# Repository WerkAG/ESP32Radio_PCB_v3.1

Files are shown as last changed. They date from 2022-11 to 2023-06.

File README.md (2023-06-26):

# ESP32Radio-V2, PCB v3.x
## Printed Circuit Board for the [ESP32Radio-V2 from Ed Smallenburg](https://github.com/Edzelf/ESP32Radio-V2)

Updates:
- 2023-06-26, PCB v3.1 Rev C assembled with all SMD parts is now available by request. 
- 2022-11-06, PCB v3.1 Rev C

 ** **
 
As microcontroller this PCB uses the MH ET LIVE ESP32MiniKit.<br> 
The PCB is designed to allow the use of one mini amplifier module (PAM8403) and/or a bluetooth transmitter module (kcx_bt_emitter).<br>
There are connectors for the supported display types (TFT, LCD, Nextion not tested), the rotary encoder, the IR receiver plus a expansion port with pins connected to GPIO12, GPI013, GPIO14 and GPIO34. MISO, MOSI, SLCK pins are also available on the expansion port.<br>
Circuit to turn ON/OFF the TFT backlight is also implemented. Control is done by the ESP32Radio software.<br>
Power supply is 5V DC.<br>
<br>

ESP32_WebRadio_PCB_v3 2_02
 <br>
 ** **

**Example of one unit using the PAM8403 amplifier.** <br><br>
The black wire on the picture isn't a patch, it connects the Analog GND (GBUF) from the VS1053 through a 47uF capacitor to VREF (pin 8) of the PAM8403 chip. This effectively cancels any noise on the speakers.<br>
Many hobbyists are hiding the huge problem of connecting an amplifier directly to the output of the VS1053B module. Everyone plugs in the headphones or amplifiers with a separate power supply and is happy with it. The problem is that as soon as you connect an amplifier with common ground to the VS1053 module, you hear very strong digital noise, which even drowns out the useful signal.<br>

ESP32_WebRadio_PCB_v3 2_03
 <br>
 ** **

**Example of a second unit using the kcx_bt_emitter bluetooth module.** <br>


<br>

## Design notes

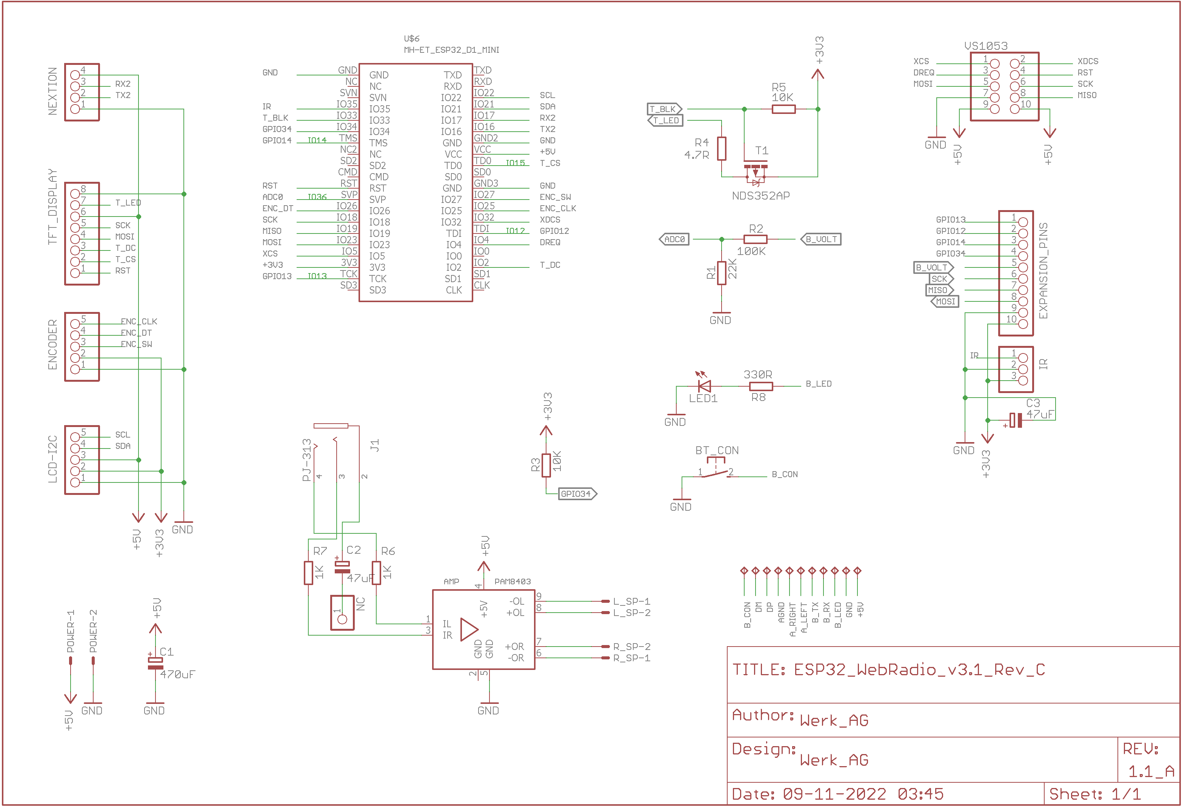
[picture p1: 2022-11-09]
doc/ESP32Radio_PCB_v3.1_Rev_C_Schematic.png

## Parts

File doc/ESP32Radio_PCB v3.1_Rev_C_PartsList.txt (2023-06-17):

ESP32Radio PCB v3.1 Rev C

PARTS LIST

RESISTORS SMD 0805
R1 22K
R2 100K
R3 10K
R4 4.7R
R5 10K
R6 1K
R7 1K
R8 330R

CAPACITORS
C1 470uF/16V
C2 47uF/16V
C3 220uF/16V

TRANSISTORS
T1 NDS352AP

LED
3mm Blue Led (optional)

MISC PARTS
MH ET LIVE ESP32MiniKit
VS1053 module
3.5mm Stereo Jack PJ-313
everal 2.54mm male pin headers
3 x KF128 2 pin screw connectors (2.54mm)
Push Buttom (optional)

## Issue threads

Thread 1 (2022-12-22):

KCX_BT_EMITTER details

willemneethling, 2022-12-22:
Thanks for providing your design. I am interested in your use of the KCX_BT_EMITTER. I checked your schematic but I don't see the BT module listed, other than a mention of the BT connect button. Also, as far as I know, Edzelf ESP radio doesn't support this module, did you change the code to support it? If so, is it possible to share the schematic and code changes?

WerkAG, 2022-12-23:
Hi,

To use the KCX_BT_EMITTER, there is no need to do any change on the original software from Edzelf ESP32Radio software. Instead of use the PAM8403, just solder the KCX_BT_EMITTER on the PCB. The BT button is only for pairing the KCX_BT_EMITTER module with your speakers or BT receiver.
Thank you for your interest on this PCB.

willemneethling, 2022-12-30:
Thank you very much for the clarification

WerkAG, 2022-12-30:
As this info can be useful to others, let's keep it open.

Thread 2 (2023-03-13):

Do I need the SMD parts?

HaViGit, 2023-03-13:
Thanks for sharing the PCB, I'm about to order from JLCPCB. Just a question in advance, I have only little experience with SMD soldering and wonder if I need the resistors and transistors. It is planned to use Ed's radio without a PAM amplifier, but with the rotary encoder, the BlueTFT and perhaps the Bluetooth transmitter (which needs SMD mounting).

I like to hear from you!

WerkAG, 2023-03-13:
Hi,

Thanks for your interest on this PCB.
At least you will need to install R4, R5 and T1, otherwise the TFT backlight will not lit.

Rgs.

HaViGit, 2023-03-13:
Thanks for your reply. Maybe it's time for me to gain experience with SMD techniques and your PCB is a good and pleasant reason. So today I ordered the PCB, SMD tools including a hotplate and the necessary parts ;-)

WerkAG, 2023-03-14:
Soldering SMD parts its easy than it seems, you only need a soldering iron with a thin point, and a magnifying glass. If you would like post a picture of the end result.
Thank you.
Rgs.

HaViGit, 2023-03-14:
If the end result is neat I'll post a picture ;-)

WerkAG, 2023-03-14:
👍

HaViGit, 2023-03-30:
Here's the result of my first SMD project, I'm not disappointed. The resistors R1 and R2 are not mounted because I do not use the voltage divider.

Thanks for sharing the Gerber!

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

WerkAG, 2023-03-31:
It looks pretty good. Soon will be finished and playing music. Thank you too for the picture.

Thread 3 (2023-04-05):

Bluetooth issues

HaViGit, 2023-04-05:
Did you discover issues using the Bluetooth transmitter? Please see https://github.com/Edzelf/ESP32Radio-V2/issues/92.

WerkAG, 2023-04-06:
Can you post a link to the specs of the Bluetooth transmitter module you are using? It is not an KCX_BT_EMITTER module like the ones I'm using, but I suppose you have checked compatibility. Yours seems to have a jumper to set RX / TX mode, is it in TX mode?

HaViGit, 2023-04-06:
I bought the BT module from AliExpress (see below) and I hadn't noticed that it was different from yours. The PIN layout is the same and if the jumper is open it is in TX mode so that should be OK. If I see correctly, the chip is a BPOW17, but I can't find anything about it on the Internet, so no datasheet either. Perhaps this BT module only works after receiving AT commands.

Maybe it's better to order the module you use and see if that works.

[https://www.aliexpress.com/item/1005003224071356.html](url)

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

WerkAG, 2023-04-08:
From what I saw from your link, your module is  newer (v1.7 bluetooth 5.1) than  mine, which is v1.1 bluetooth 4.1. As you said pinout is the same, so I suppose it should work too. Is the LED linking in RED or BLUE? From specs RED means TX.
I had some difficulties on pairing mine with some devices, but once paired I got sound.

HaViGit, 2023-04-08:
I would also be surprised if the two version modules are not compatible, nevertheless I ordered two like you used to make sure that is not the issue.

The LED does indeed flash red and after pairing the LED on your PCB will also turn on. When I turn the earbuds or headphones on or off, that LED responds as expected. So I don't think pairing is the problem.

Anyway I will have to wait for the new BT modules to arrive, I will let you know what the result is afterwards.

HaViGit, 2023-04-08:
Thank you for your message. I know it is sometimes difficult to pair BT but the pairing works fine, just no sound. In the meantime I tested with Samsung Earbuds, a Sony Headphone and a set of very cheap earbuds from AliExpress. I can pair them all, pretty quickly, but no sound.

Maybe I have a faulty module, maybe there is another problem with my version. All I can do now is to be patient and wait for the old version to be delivered. Besides the radio works well through a pair of wired speakers ;-)

WerkAG, 2023-04-10:
It should not make any difference, but try to remove the C2 cap, it isn't needed for bluetooth operation.

HaViGit, 2023-04-10:
As you expected, it made no difference. I'm patient so now wait a while until the other module is received.

HaViGit, 2023-04-20:
Today the ordered BT modules were delivered, but contrary to what was advertised on AliExpress, they did not send the old but the new version. So I don't get anywhere with that, I opened a dispute on AliExpress. In short, I can't go on with it. I'm going to put this project on hold for now :-(

WerkAG, 2023-04-20:
I'm so curious, that as soon as possible I will order one of these new versions.

HaViGit, 2023-04-25:
After I paired my earbuds with the BT module, I still didn't hear any music on the earbuds. But while I was doing some testing and experimenting I accidentally connected AGND on the BT module to GND (power negative) of the ESP-32 board. Immediately afterwards, playback started on my earbuds.

To exclude that I did something wrong during the soldering and to be sure that I did not use a defective BT module, I built a second radio. There too BT audio only worked after I made a permanent connection between GND and AGND.

I assume this has to do with the newer version of the BT module, after all I used a different one than you (see above). Anyway, my project is now successful!

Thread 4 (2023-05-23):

Type of capacitor

z34pec, 2023-05-23:
Hello. In your explanation is said to connect cap 74uF but it is not defined is it electrolytic or normal, block (ceramic) and voltage of it  ?
On your pic I see only electrolytic so I suppose it is electrolytic up to 16v or more ?
Also

WerkAG, 2023-05-25:
Hi. I used 47uF electrolytic, and it worked fine. I think you can use also 33uF or even 22uF.
Thanks.

z34pec, 2023-05-27:
Hello.
Thank you for explanation.
I check vs1053 documentation and it says GBUF is GND from output to headphones, right ?
So I have to connect this capacitor between GND of headphones and pin 8 of PAM8403 chip, right ?

WerkAG, 2023-05-28:
If you are using the PCB, use a small wire to connect the point marked with NC on the PCB to pin 8 of PAM8403 chip, if not,  connect the GND (that is GBUF) from output to headphones on the vs1053 module to positive pole of the capacitor and the negative pole to pin 8 of PAM8403 chip.

z34pec, 2023-05-28:
Thank you for your response.
I will do it as soon as possible.
73 de Z34PEC
Petrika

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

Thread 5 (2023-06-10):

5V dc source

RobiDobo, 2023-06-10:
Can I do this without having a 5v dc source? Other esp32 dev boards have the pin for 5V but I dont see it on this one. Can I use a normal esp32 and power it externally? The design looks really good too, sorry if this is offtopic i'm a beginner.

WerkAG, 2023-06-12:
The ESP32 board used on this project also have a 5V input pin. You will need a 5V DC source, that you can connect to the 5V power input on the PCB.
Thanks.

RobiDobo, 2023-06-12:
Thanks much.

RobiDobo, 2023-06-12:
Also, can you please tell me if I can use a PAM8403 with a built in potentiometer?

WerkAG, 2023-06-13:
If you understood what is said about the common ground issue and know how to correctly connect the PAM8403 with a built in potentiometer, I think you can. I just can comment on this project as it is, any changes you need to try by yourself.

Any 5V power supply with at least 1Amp should work.

RobiDobo, 2023-06-13:
I think I understand, looking at a couple of projects some use audio transformers to eliminate the noise, while you use capacitors. I will try this, thank you a lot for the files and help.

WerkAG, 2023-06-15:
The trick is not the capacitor, but not mix the GND of the general circuit with the Analog GND (GBUF) from the VS1053.

RobiDobo, 2023-06-15:
That makes sense! Thank you for clarification. I can't help but notice in the part list it says 0806 SMD resistors, but on the internet i could only find 0805 SMD. What's the deal there?

WerkAG, 2023-06-17:
You are helping :-) The resistors are 0805, it was a typo error. Already corrected, thank you.

Closed 2023-09-24.

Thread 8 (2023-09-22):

LineIn

RobiDobo, 2023-09-22:
How do you connect the vs1053 on the pcb? I have the LINE IN pins sticking out.

WerkAG, 2023-09-22:
The easy way is using a small cable with a male jack on both ends. LINE OUT of the VS1053 to LINE IN on the board. See the pictures, they illustrate it better than my words.

RobiDobo, 2023-09-22:
Thank you but I still can't see what to connect it to. LINE IN of vs1053 should go to Line out on the board right? But I can't see anything labelled as "line out" or "line in" on the pcb. Pls help I'm confused where to look even after reading several times :)

WerkAG, 2023-09-23:
The 3.5mm stereo jack on the board is the LINE IN. The 3.5mm jack on the VS1053 in LINE OUT. Just connect the two with a small 3.5mm stereo male-male cable

Note: The reason for having the small the 3.5mm stereo jack on the board is to allow the device to work with other sound sources than just the VS1053. It will amplify or transmit by Bluetooth whatever you put on the LINE IN of the board.

Sorry for my poor English.

RobiDobo, 2023-09-23:
Ah okay I see, I will do that but there are also 2 pins on the VS1053 beneath which is written LINE IN and I don't see anything in the scheme what to do with those. Don't worry, your english is very clear.

WerkAG, 2023-09-23:
The line in pins on the VS1053 (decoder board) aren't used for anything.

RobiDobo, 2023-09-23:
then should I cut them or how do i fit the vs1053 on the pcb? use female headers and leave those pins sticking out?

RobiDobo, 2023-09-23:
Thank you very much for bearing with me :)

WerkAG, 2023-09-23:
Yes, use female headers on the PCB, then fit the VS1053 module on them. The VS1053 module will be removable.
I suggest to also use female headers for the microcontroller.
:-)

RobiDobo, 2023-09-24:
Thank you!

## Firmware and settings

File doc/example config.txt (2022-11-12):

clk_dst = 1                 # Offset during daylight saving time (hours)
clk_offset = 0              # Offset with respect to UTC in hours
clk_server = pool.ntp.org   # Time server to be used
#
ir_02FD = preset = 25       # Button 4
ir_20DF = mute
ir_38C7 = preset = 1        # Button 1
ir_40BF = upvolume = 2
ir_609F = uppreset = 1
ir_629D = preset = 9        # Button 9
ir_A25D = preset = 23       # Button 8
ir_C03F = downvolume = 2
ir_E01F = downpreset = 1
ir_E21D = preset = 0        # Button 8
#
mqttbroker = none
mqttpasswd = none
mqttport = 1883
mqttprefix = none
mqttuser = none
#
pin_enc_clk = 25           # GPIO Pin for rotary encoder "CLK"
pin_enc_dt = 26            # GPIO Pin for rotary encoder "DT"
pin_enc_sw = 27            # GPIO Pin for rotary encoder "SW"
pin_ir = 35                # GPIO Pin for IR receiver VS1838B
pin_tft_blx = 33
pin_tft_cs = 15            # GPIO Pin for TFT "CS"
pin_tft_dc = 2             # GPIO Pin for TFT "DC"
pin_vs_cs = 5              # GPIO Pin for VS1053 "CS"
pin_vs_dcs = 32            # GPIO Pin for VS1053 "DCS"
pin_vs_dreq = 4            # GPIO Pin for VS1053 "DREQ"
#
preset = 11
preset_000 = pianosolo.streamguys.net/live                      # 00- Solo Piano Radio
preset_001 = radiocast.rtp.pt/antena180a.mp3                    # 01- Antena 1
preset_002 = radiocast.rtp.pt/antena280a.mp3                    # 02- Antena 2
preset_003 = radiocast.rtp.pt/antena380a.mp3                    # 03- Antena 3
preset_004 = mcrscast.mcr.iol.pt/m80                            # 04- M80
preset_005 = mcrscast.mcr.iol.pt/smoothfm                       # 05- Smooth FM
preset_006 = 20863.live.streamtheworld.com/RFM_SC               # 06- RFM
preset_007 = tsfdirecto.tsf.pt/tsfdirecto.mp3                   # 07- TSF
preset_008 = radiocast.rtp.pt/antena2jazzin80a.mp3              # 08- JazzIn
preset_009 = strm112.1.fm/rockclassics_mobile_mp3               # 09- 1.FM Classic Rock
preset_010 = streaming.hotmix-radio.net/hotmixradio-90-128.mp3  # 10- Hotmix Radio 90s
preset_011 = airspectrum.cdnstream1.com:8114/1648_128           # 11- Easy Hits Florida 128k
preset_012 = airspectrum.cdnstream1.com:8000/1261_192           # 12- Magic Oldies Florida
preset_013 = strm112.1.fm/crock_mobile_mp3                      # 13- 1.FM Classic Rock Replay
preset_014 = 178.32.111.41:8039/stream-128kmp3-HealingMusic     # 14- Relaxing Music
preset_015 = streams.radiobob.de/bob-80srock/mp3-192/streams.radiobob.de   # 15- Radio Bob
preset_016 = streamer.radio.co/sa7bf61271/listen                           # 16- JB's Rock N Roll
preset_017 = air-tunein.radioart.com/fAura.mp3                # 17- RadioArt - Aura
preset_018 = stream12.iloveradio.de/iloveradio2-aac.mp3       # 18- Radio Dance Music
preset_019 = 174.36.206.197:8000/stream                       # 19- Venice Classic Radio
preset_020 = ice6.somafm.com/suburbsofgoa-128-mp3             # 20- SomaFM - Suburbs of Goa
preset_021 = 144.217.158.59:5120/stream                       # 21- Smooth Jazz Florida
preset_022 = s2.radio.co/sc00bf91e1/listen                    # 22- Smooth Jazz South Florida
preset_023 = 101smoothjazz.cdnstream1.com/b22139_128mp3       # 23- 101 SMOOTH JAZZ
preset_024 = streaming.live365.com/b77280_128mp3              # 24- Aardvark BluesFM
preset_025 = cast3.radiohost.ovh:8352                         # 25- Blues Radio
preset_026 = ais-sa2.cdnstream1.com/1992_128.mp3              # 26- Blues Music Fan
preset_027 = ice1.somafm.com/seventies-128-mp3                # 27- SomaFM Left Coast 70s
#
toneha = 2
tonehf = 10
tonela = 8
tonelf = 14
#
volume = 44
#
wifi_00 = Aldeao/xxxxxxxxxxxxxxxxxx
wifi_01 = Meteo/xxxxxxxxxxxxx

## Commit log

2022-11-06 Create gerber
2022-11-09 Update PCB v3.1_Rev_C_PartsList.txt
2022-11-09 Update and rename PCB v3.1_Rev_C_PartsList.txt to ESP32Radio_PCB v3.1_Rev_C_PartsList.txt
2022-11-12 Update example config.txt
    [example config.txt]
2023-06-17 Update ESP32Radio_PCB v3.1_Rev_C_PartsList.txt
